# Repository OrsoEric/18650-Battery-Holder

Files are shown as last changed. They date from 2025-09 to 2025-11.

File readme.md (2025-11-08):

# 18650 Battery Holder

This is a design for a robot battery holder

# Battery with PCB protection

Length measured to the tip of the button

| Battery | Diameter [mm] | Length [mm] | Capacity [mAh] | Note |
|---|---|---|---|---|
| UltraFlre LI IONBRC  |  18 | 680 | 4800 | I think the capacity is a scam|
| RSPRO LI ION PCB |  18 | 710 | 2600 | |

# Battery Tab 

Size 11x11mm slightly bigger

| Loading | Length [mm] |
|---|---|
| Unloaded | 8 mm |
| Loaded | 3 mm |

# OpenSCAD

Modeling of the parts

## Tab with Spring

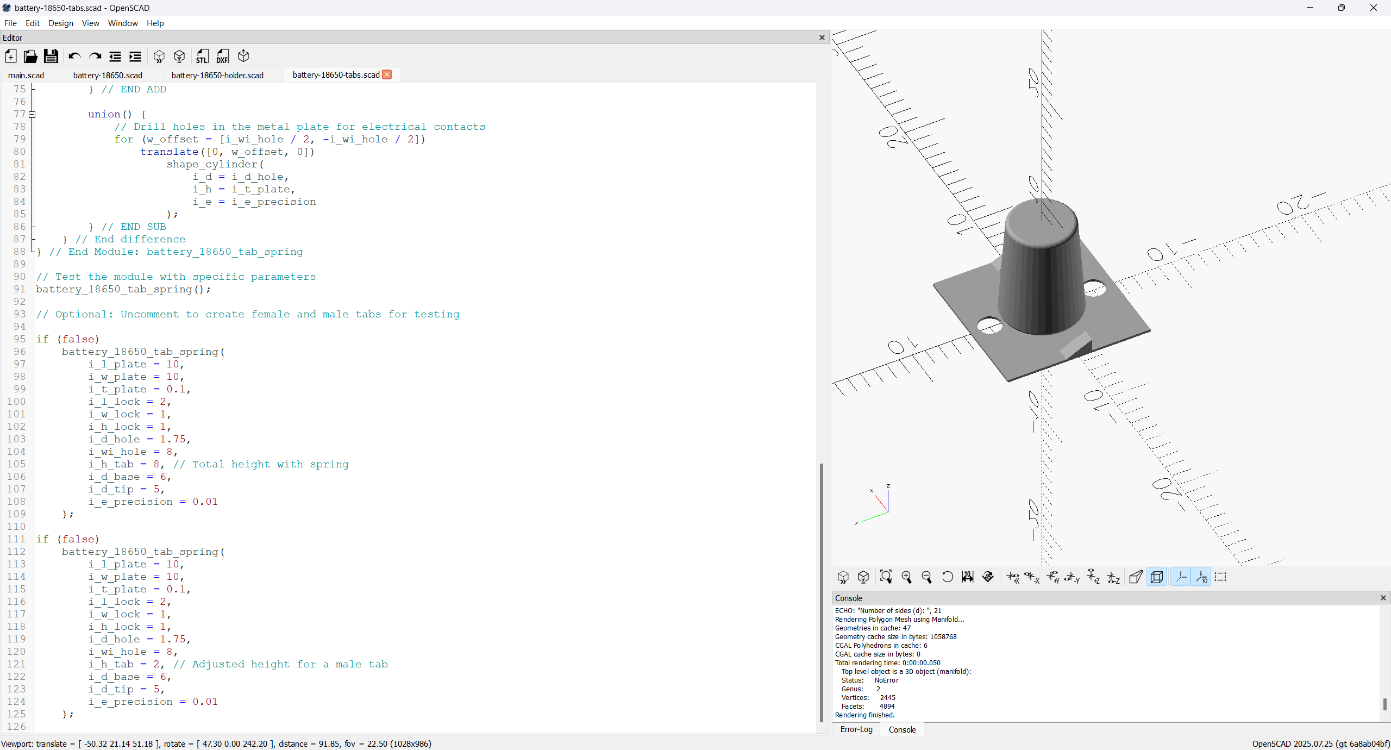
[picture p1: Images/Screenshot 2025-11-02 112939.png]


## Endcap for the battery holder

OpenSCAD

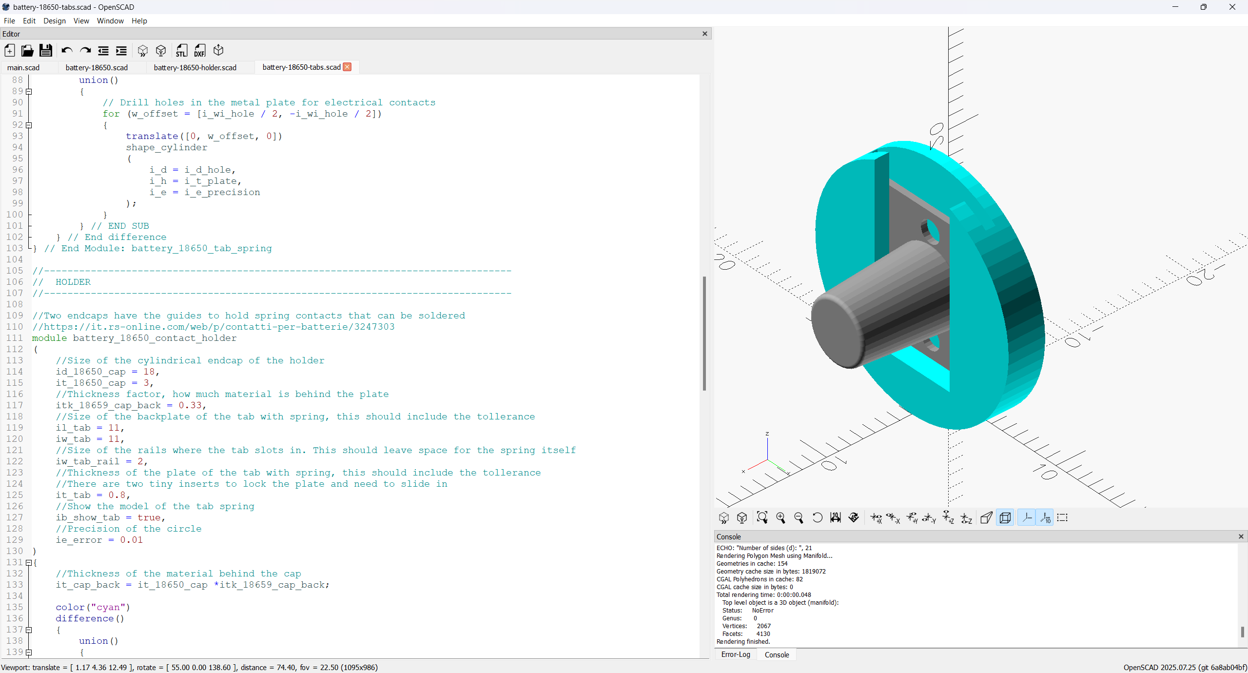
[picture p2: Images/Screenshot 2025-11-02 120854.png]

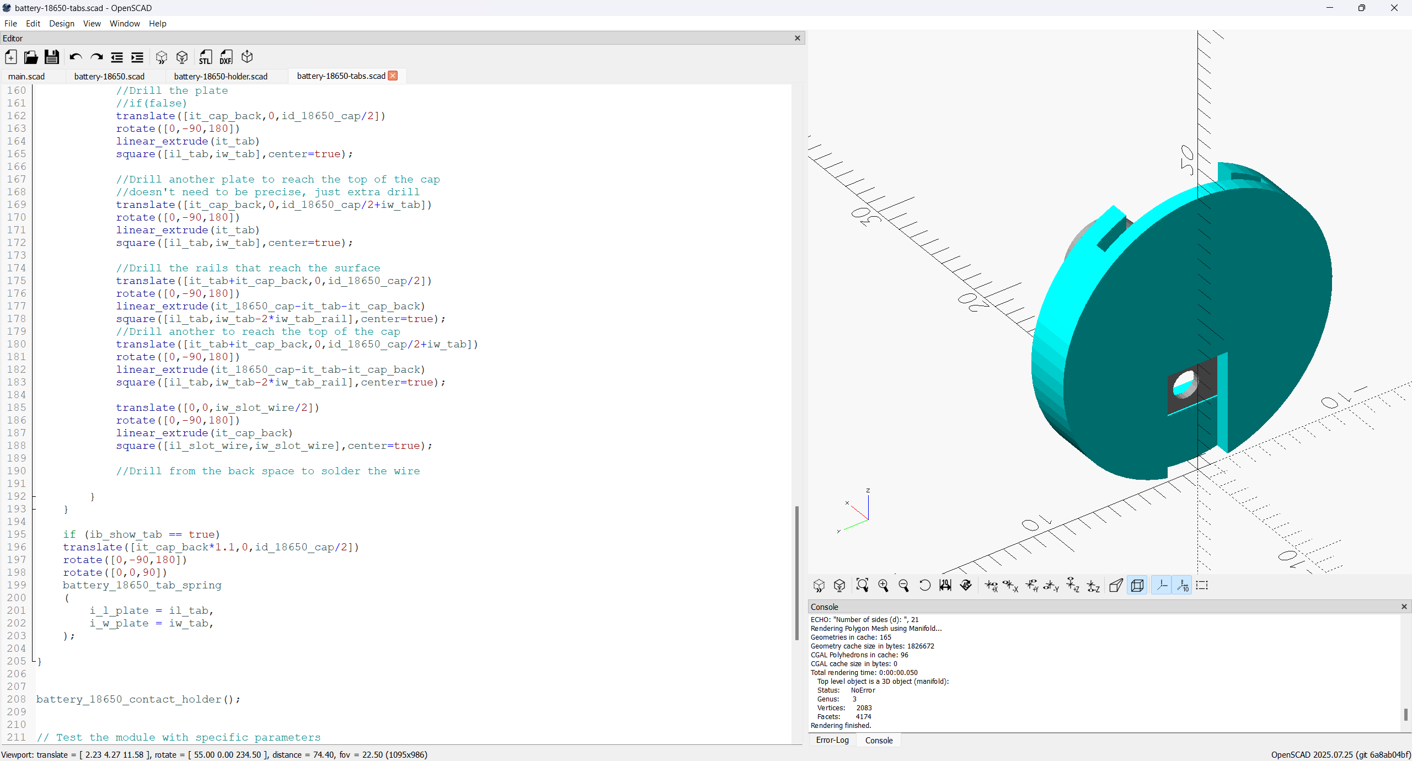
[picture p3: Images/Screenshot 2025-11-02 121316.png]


Printed to test tollerances

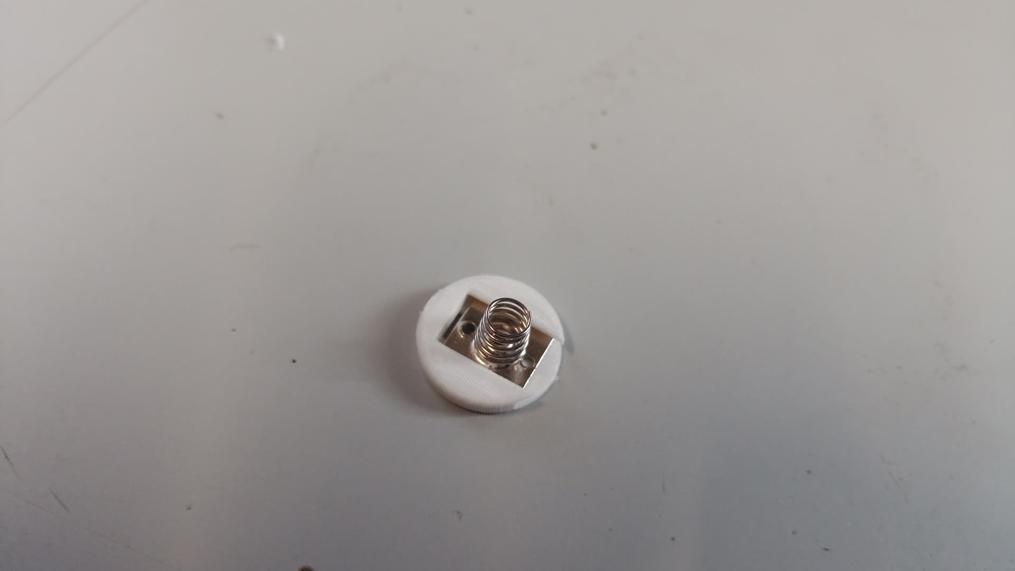
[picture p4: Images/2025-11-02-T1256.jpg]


## Holder 1S1P Single Battery

S mean series, P means parallel

3.7V nominal
4.2V max

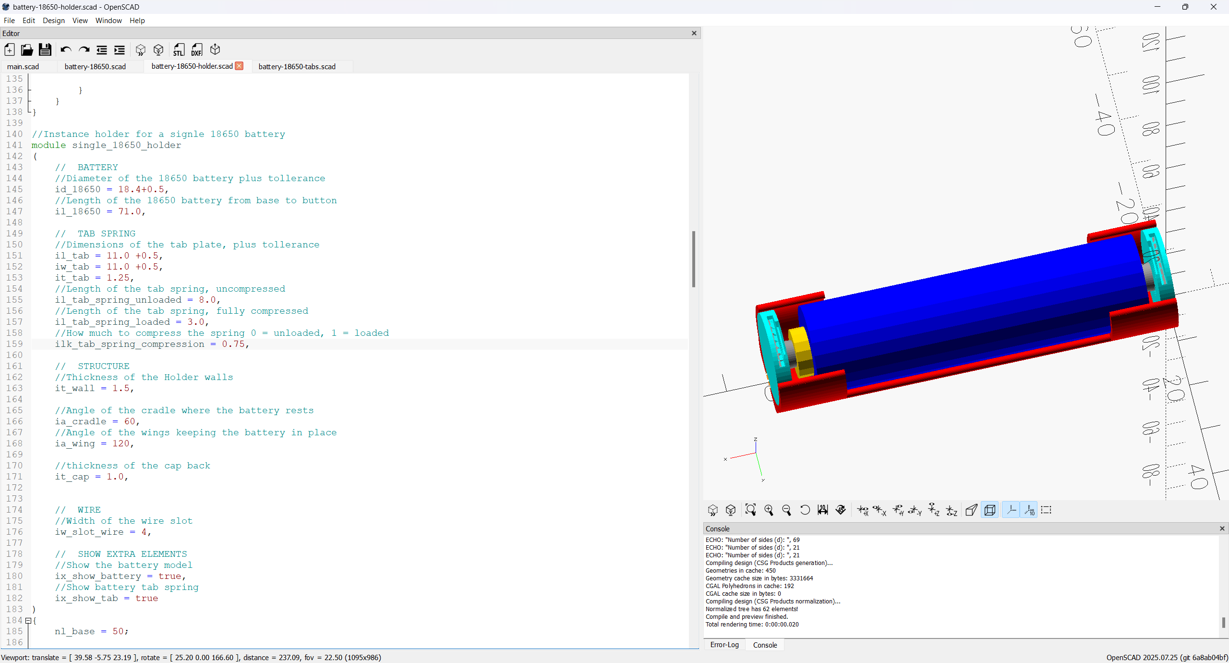
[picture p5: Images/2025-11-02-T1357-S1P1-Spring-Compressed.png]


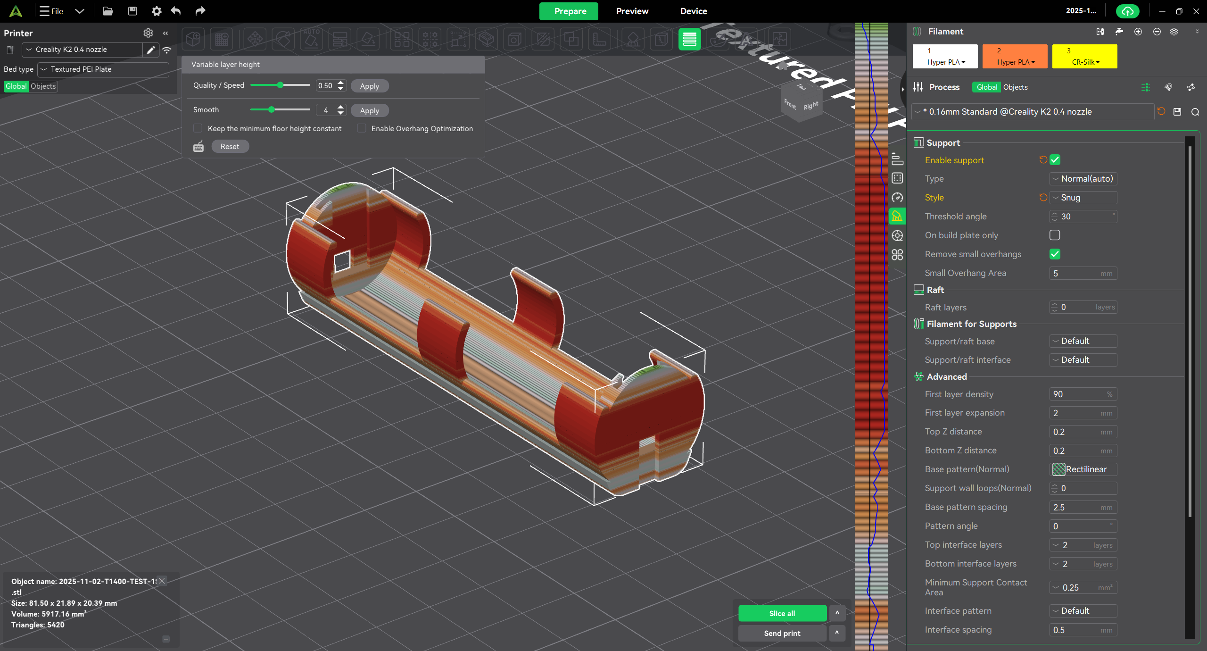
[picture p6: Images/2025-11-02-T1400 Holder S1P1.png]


First test, it's close. Fix:
- I did double spring that's not smart, I do have a button contact for the positive tab
- The center wing is too weak, I need to make it longer
- Ticker construction?

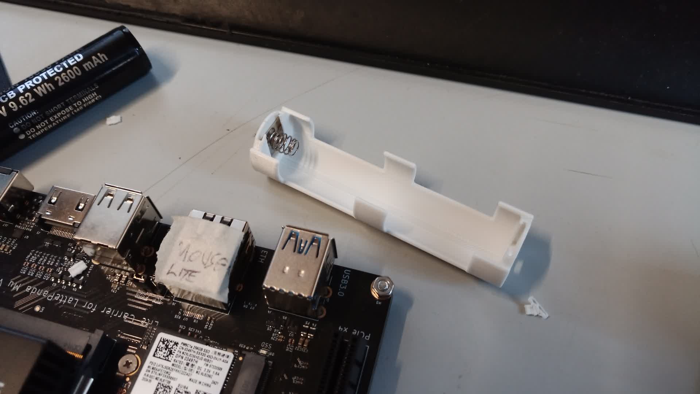
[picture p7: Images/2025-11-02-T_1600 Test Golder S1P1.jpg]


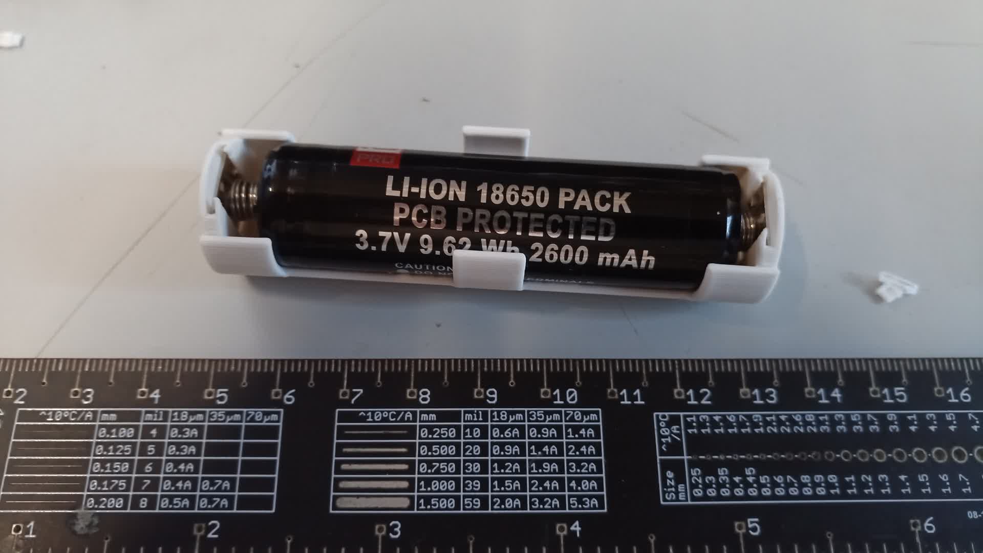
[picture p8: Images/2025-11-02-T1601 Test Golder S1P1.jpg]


## Holder 2S1P Dual Battery

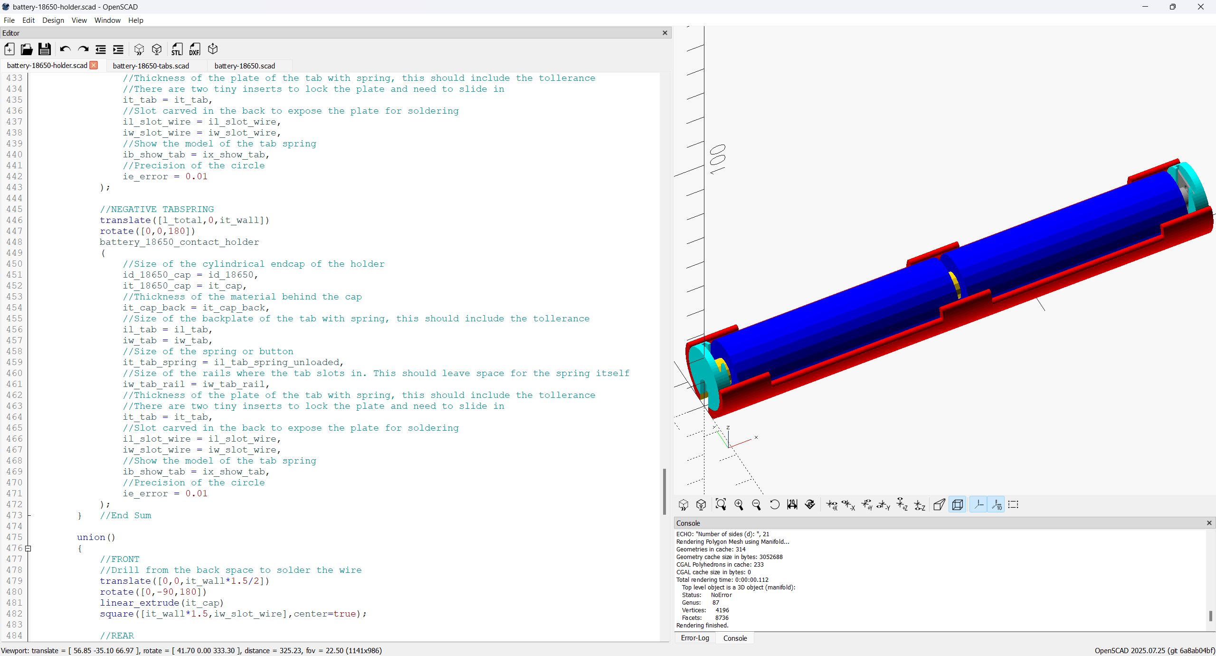
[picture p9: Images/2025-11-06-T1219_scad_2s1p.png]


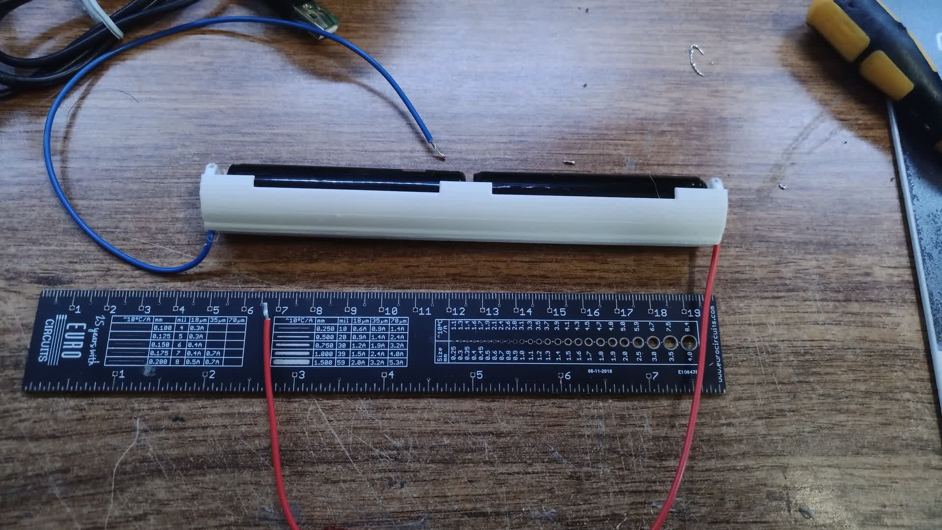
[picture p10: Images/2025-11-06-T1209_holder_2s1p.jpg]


## Holder 2S2P Quad Battery

3.7 * 4 = 14.8V nominal
4.2 * 4 = 16.8V max

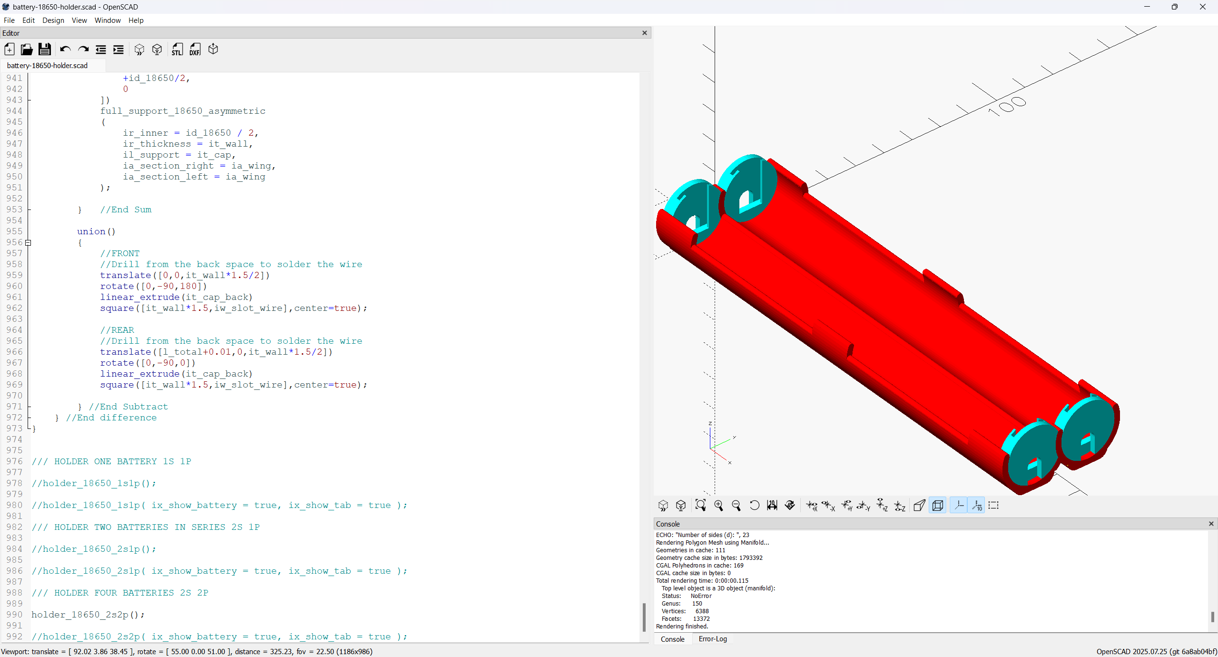
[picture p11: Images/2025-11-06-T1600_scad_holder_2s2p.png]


## Soldering

<video src="/Videos/2025-11-06_18650_Battery_Holder_1S1P_2S2P_Solder_Test.mp4" width="720" height="480" controls></video>

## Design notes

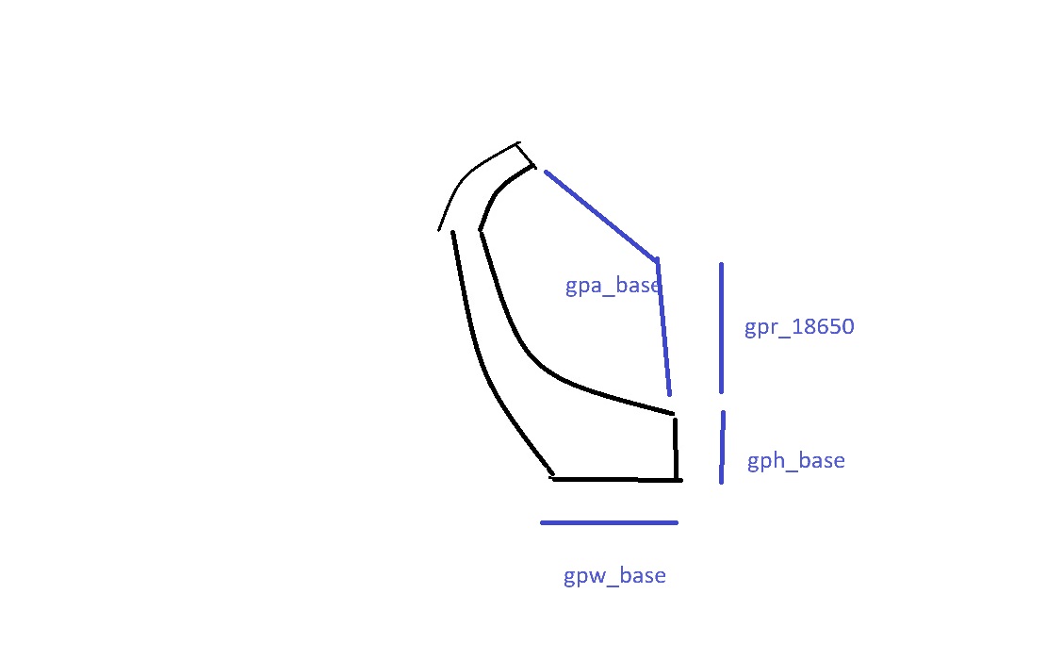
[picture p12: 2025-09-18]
Images/Support Design.jpg

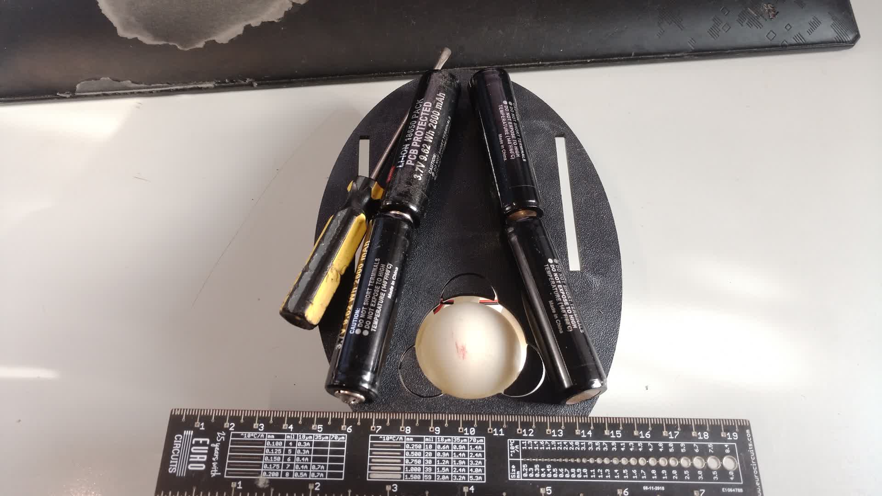
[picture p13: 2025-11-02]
Images/2025-11-02_14_44_IMG_20251102_144404.jpg

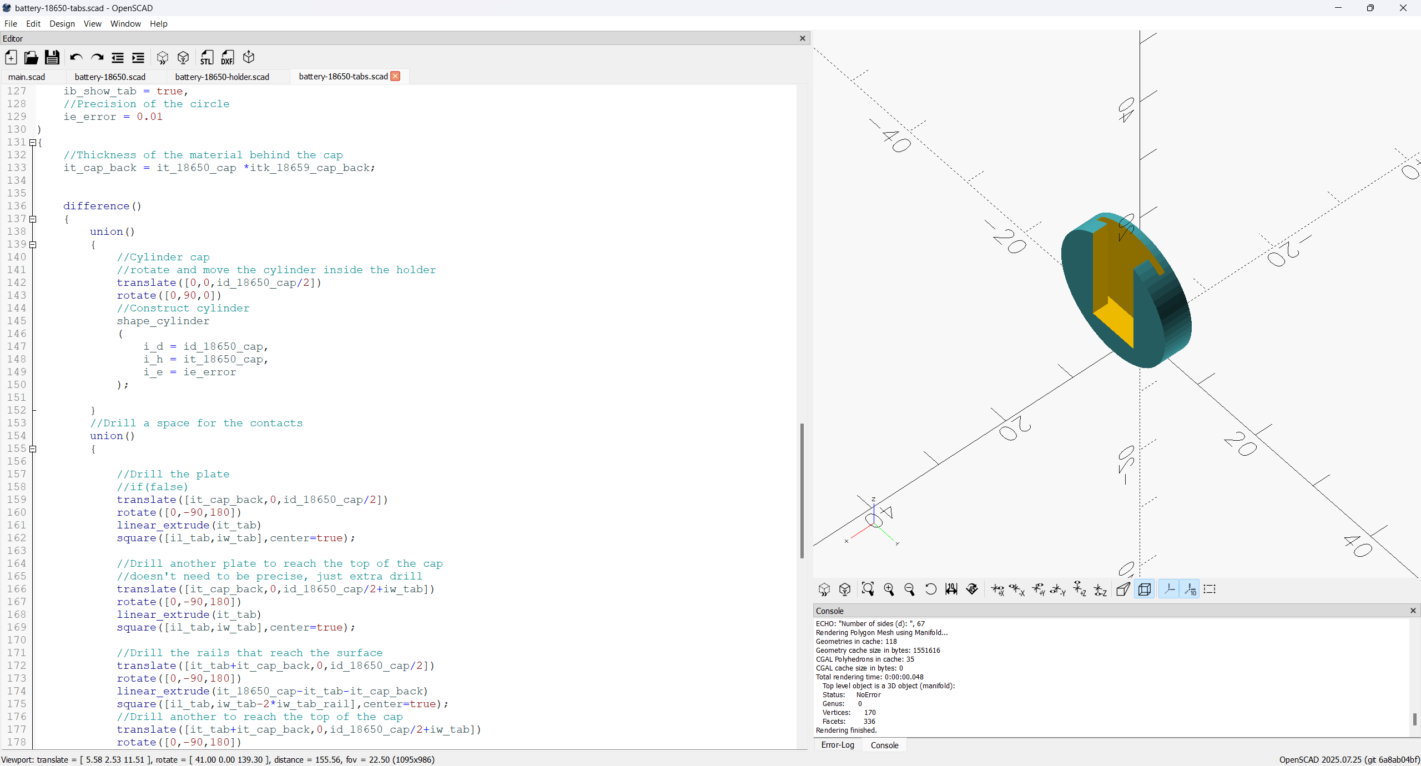
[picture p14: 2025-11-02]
Images/Screenshot 2025-11-02 120257.png

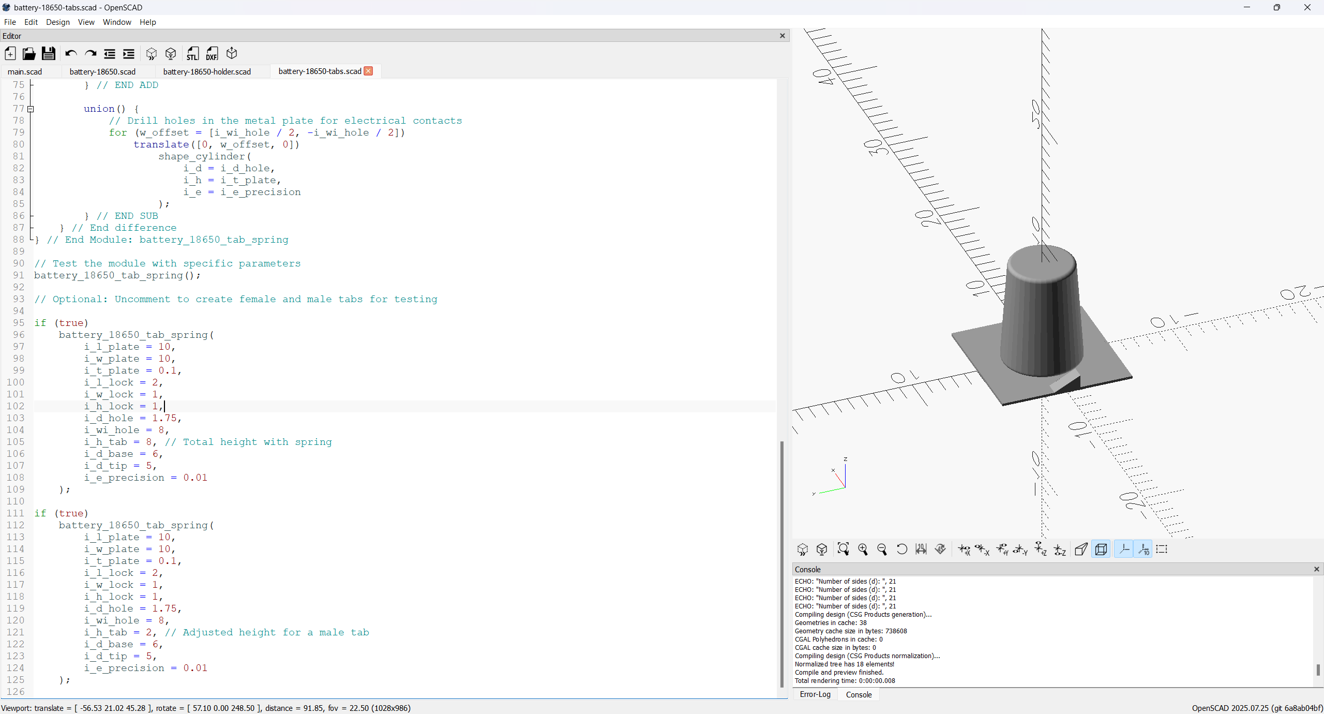
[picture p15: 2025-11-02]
Images/Screenshot 2025-11-02 112849.png

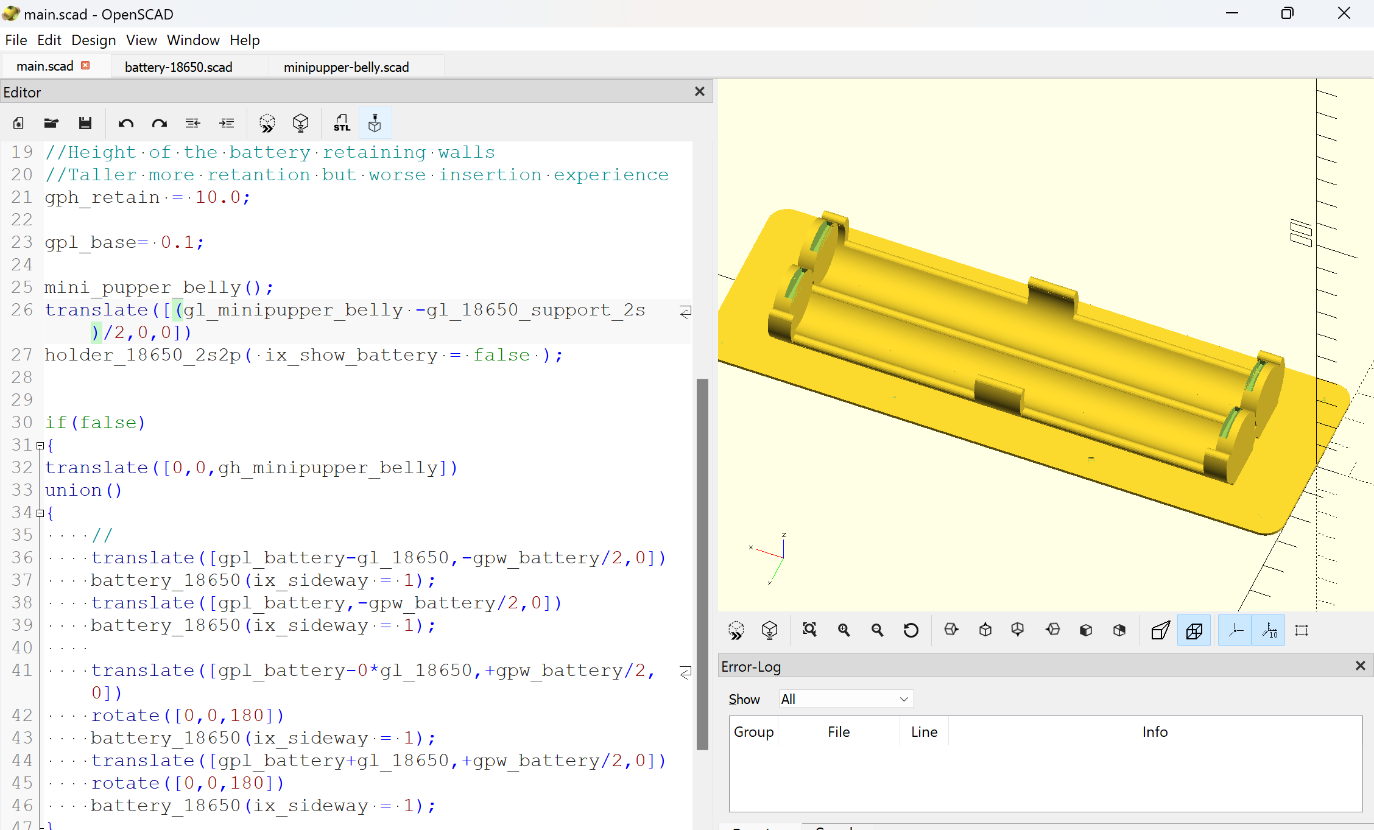
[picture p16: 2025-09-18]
Images/main.scad - OpenSCAD 2024-06-20 18_16_03.png

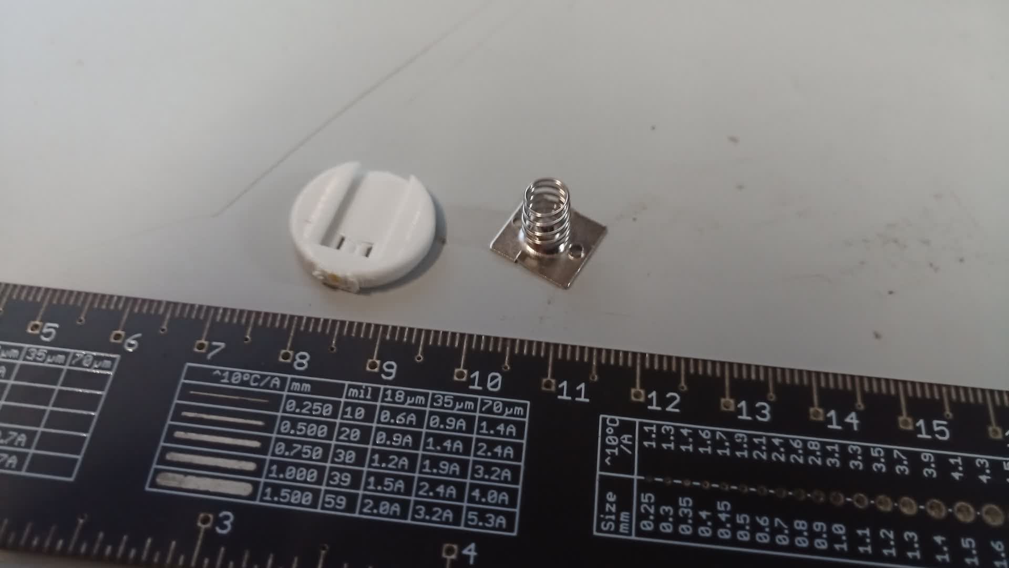
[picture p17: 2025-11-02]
Images/2025-11-02_12_37_IMG_20251102_123743.jpg

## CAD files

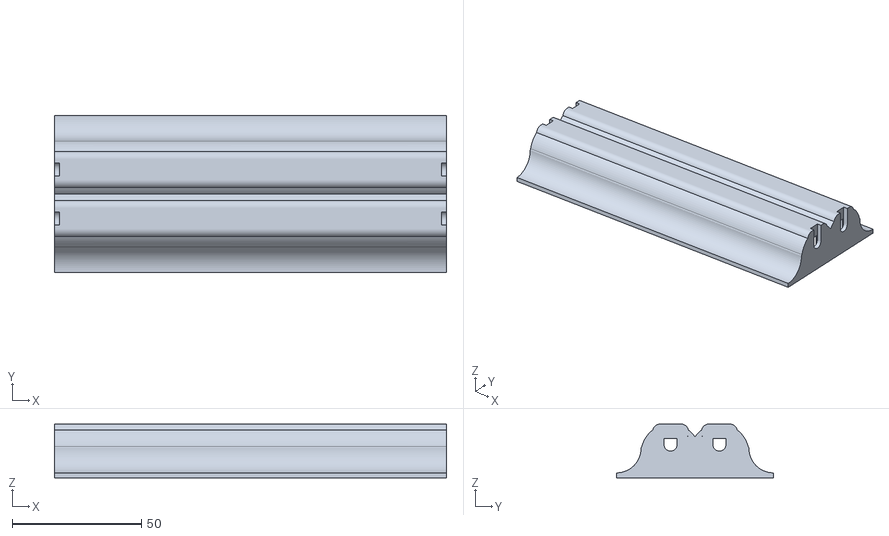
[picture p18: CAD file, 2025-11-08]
stl/2025-11-08-T1028-2S2P_inverted.stl
151.8 x 60.7 x 20.9

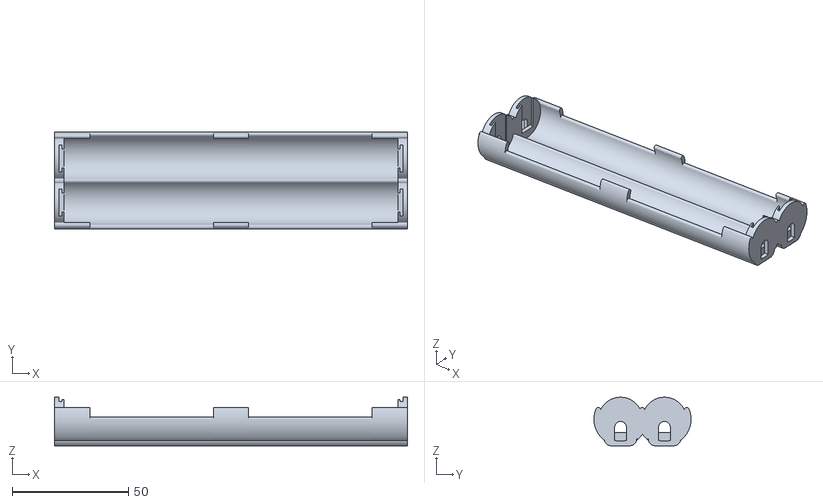
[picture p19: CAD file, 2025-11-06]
stl/2025-11-06-T1600-TEST-2S2P.stl
151.8 x 41.8 x 20.9

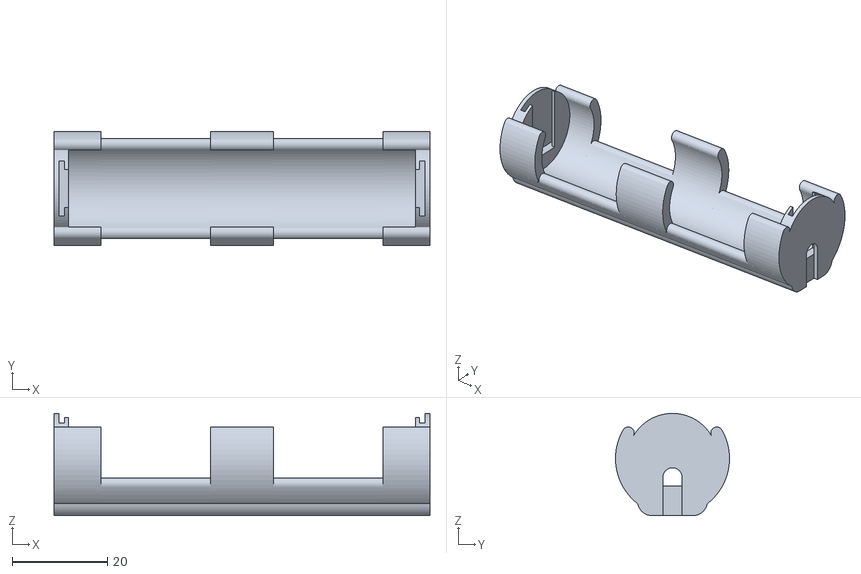
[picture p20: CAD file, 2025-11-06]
stl/2025-11-02-T1650-TEST-1S.stl
78.8 x 23.9 x 21.4

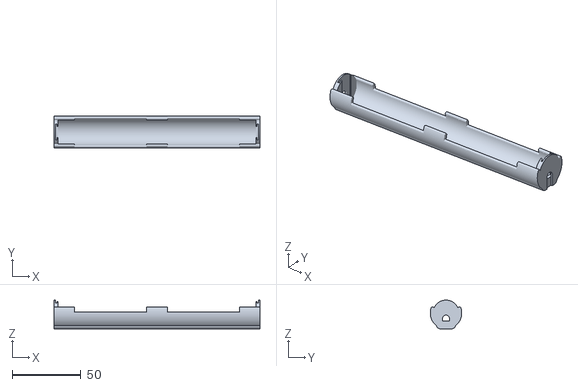
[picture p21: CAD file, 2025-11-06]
stl/2025-11-06-T1120-TEST-2S1P.stl
149.8 x 22.9 x 20.9

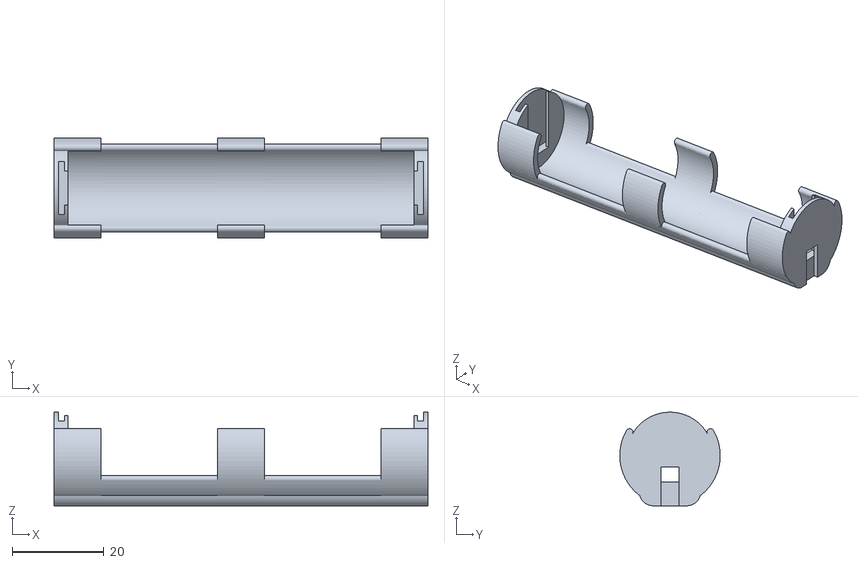
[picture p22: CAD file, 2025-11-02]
stl/2025-11-02-T1400-TEST-1S.stl
81.5 x 21.9 x 20.4

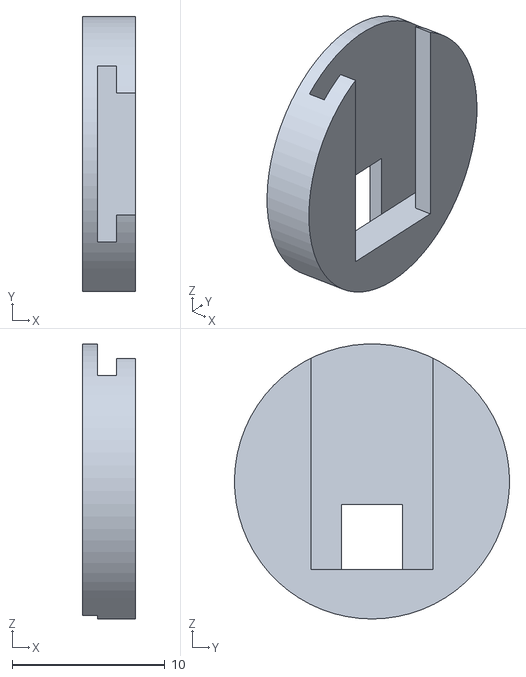
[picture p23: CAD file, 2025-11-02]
stl/2025-11-02-T1309-TEST-Tab-Spring.stl
3.50 x 18.0 x 18.0

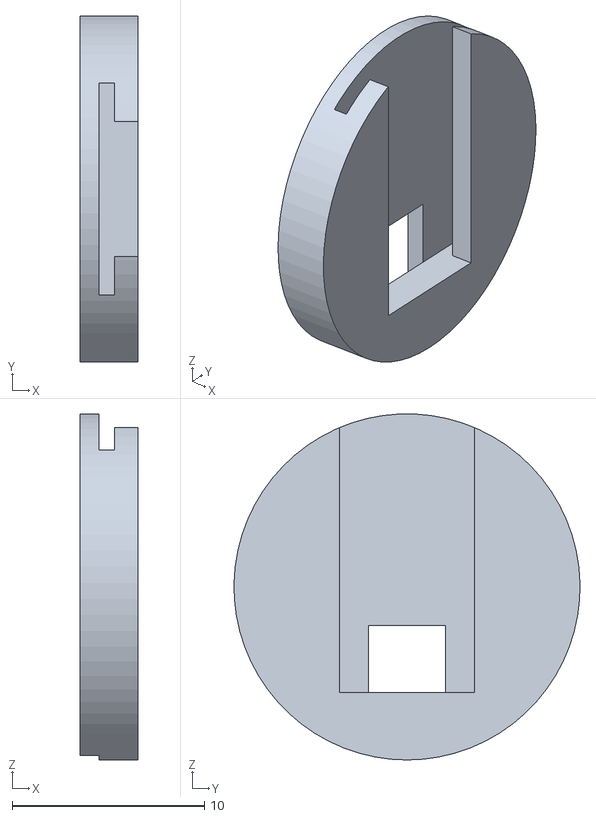
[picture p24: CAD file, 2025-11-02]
stl/2025-11-02-T1215-TEST-Tab-Spring.stl
3.00 x 18.0 x 18.0

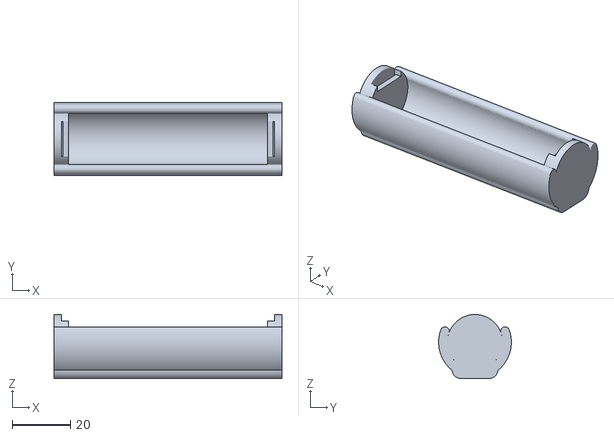
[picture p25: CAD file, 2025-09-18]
stl/2024-06-13_18_21_18650_single_prototype.stl
78.0 x 24.9 x 21.9

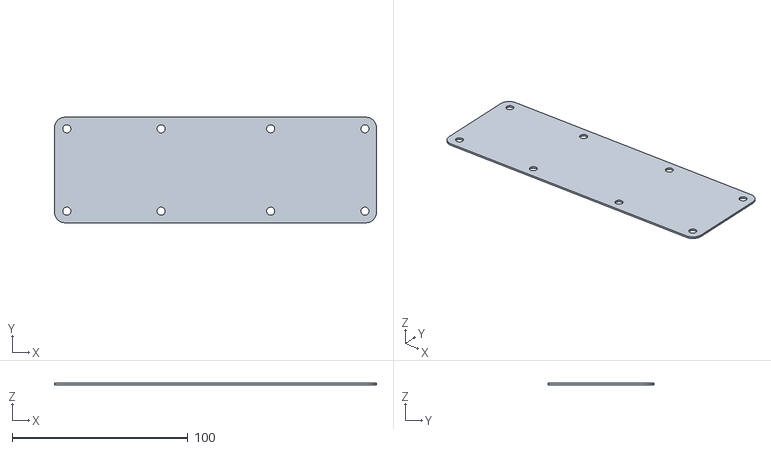
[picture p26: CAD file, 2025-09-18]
stl/2024-06-02 MP2 Belly Plate V0.stl
183.0 x 60.0 x 1.00

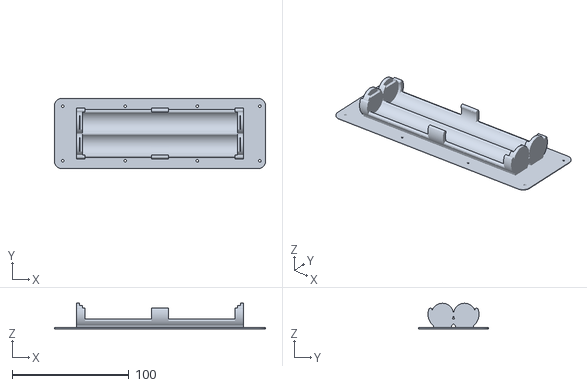
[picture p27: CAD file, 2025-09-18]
stl/2024-06-20_18_17-2s2p-prototype.stl
181.0 x 60.0 x 21.9

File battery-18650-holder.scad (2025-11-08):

include <libs/polyround.scad>

include <libs/shape_petal.scad>

include <battery-18650.scad>

//Include the geometry for the tab that contact with the battery, and the endcap of the battery holder
include <battery-18650-tabs.scad>

//	2024-06-23
//	Printed but too short for the batteries

//ia_section = controls the strength of the support. 0 is none. 90 comes up to half battery. the more up the more it retains, but the harder it is to insert
//Fixed the shape of the base to be more scalable with wall thickness, now works from 1 to 3
module half_support_18650
(
	ir_inner,
	ir_thickness,
	il_support,
	ia_section
)
{
    aan_points =
	([
        //Origin
        [0,0,0],
        [0,ir_thickness,0],
		[-ir_inner*0.5 -ir_thickness*0.7,ir_thickness,3],
        [-ir_inner*0.6 -ir_thickness*0.9,-0.2*ir_inner,0],
		[-ir_inner*0.3 -ir_thickness*0.4,-0.0*ir_inner,0],
        [-ir_inner*0.5 -ir_thickness*0.7,-0.0*ir_inner,0],
    ]);  

    //Place the base under the battery housing
    translate([0,0,ir_thickness])
    rotate([-90,0,-90])
    //Construct base
    linear_extrude(il_support)
    polygon(polyRound(aan_points,100));

	shape_petal
	(
		i_r_inner = ir_inner,
		i_r_thickness = ir_thickness,
		i_l_length =il_support,
		i_a_angle = ia_section,
		i_e = 0.01
	);
}

if (false)
half_support_18650
(
	ir_inner = (18.4+0.5)/2,
	ir_thickness = 1.0,
	il_support = 20,
	ia_section = 60
);


//Support around a full battery
module full_support_18650
(
	ir_inner,
	ir_thickness,
	il_support,
	ia_section,
)
{
    half_support_18650(ir_inner, ir_thickness, il_support, ia_section);

    //left wing
    translate([il_support,0,0])
    rotate([0,0,180])
    half_support_18650(ir_inner, ir_thickness, il_support, ia_section);
}

//Support around a full battery
module full_support_18650_asymmetric
(
	ir_inner,
	ir_thickness,
	il_support,
	ia_section_right,
	ia_section_left
)
{
    half_support_18650(ir_inner, ir_thickness, il_support, ia_section_right);

    //left wing
    translate([il_support,0,0])
    rotate([0,0,180])
    half_support_18650(ir_inner, ir_thickness, il_support, ia_section_left);
}

//Instance holder for a signle 18650 battery
module holder_18650_1s1p
(
	//	BATTERY
	//Diameter of the 18650 battery plus tollerance
	id_18650 = 18.4+0.5,
	//Length of the 18650 battery from base to button
	il_18650 = 71.0,

	//	TAB SPRING/BUTTON
	//Dimensions of the tab plate, plus tollerance
	il_tab = 11.0 +0.5,
	iw_tab = 11.0 +0.5,
	//Thickness of plate slot
	it_tab = 1.25,
	//Size of the button of the tab
	it_tab_button_positive = 1.5,
	//Length of the tab spring, uncompressed
	il_tab_spring_unloaded = 8.0,
	//Length of the tab spring, fully compressed
	il_tab_spring_loaded = 3.0,
	//How much to compress the spring 0 = unloaded, 1 = loaded
	ilk_tab_spring_compression = 0.75,
	//Rails
	iw_tab_rail = 1.75,

	//	STRUCTURE
	//Thickness of the Holder walls
	it_wall = 2.0,
	//Length factor of the wings 10 means 1/10 of length. 5 mean 1/5 of length
	ilk_wing = 6,


	//Angle of the cradle where the battery rests
	ia_cradle = 90,
	//Angle of the wings keeping the battery in place
	ia_wing = 110,
	
	//Thickness of the cap plus rails
	it_cap = 4.0,
	//thickness of the cap back
	it_cap_back = 2.0,
	


	//	WIRE
	//Lentgh of the wire slot
	il_slot_wire = 6,
	//Width of the wire slot
	iw_slot_wire = 5,

	//	SHOW EXTRA ELEMENTS
	//Show the battery model
	ix_show_battery = false,
	//Show battery tab spring
	ix_show_tab = false
)
{
    nl_base = 50;

	//Compute the spring compression length when battery is placed
	il_tab_spring = il_tab_spring_loaded + (il_tab_spring_unloaded -il_tab_spring_loaded)*(1-ilk_tab_spring_compression);
	
	echo("Spring loading",il_tab_spring);
	//Total length of the battery holder. account for the full stack
	l_total = il_18650 + it_cap_back + it_tab_button_positive + il_tab_spring + it_cap_back;

    //battery
    if (ix_show_battery == true)
    {
        //translate([(l_total-il_18650)/2,0,it_wall])
		translate([it_cap_back+it_tab_button_positive,0,it_wall])
        battery_18650
		(
			// Barrel Dimensions
			i_l_18650 = il_18650,
			i_d_18650 = id_18650-0.5,
			ix_sideway = 1,
			in_invert_poles = true
		);
    }
    
    //I use two sets of wings
    //short wings to retain the battery aligned
    //Tall wings to clip the battery in place

	difference()
	{
		union()
		{
			//Retaining wing butt
			color("red")
			full_support_18650
			(
				id_18650 / 2,
				it_wall,
				l_total / ilk_wing,
				ia_wing
			);

			//Retaining wing front
			color("red")
			translate([l_total *(1 -1/ilk_wing),0,0])
			full_support_18650
			(
				id_18650 / 2,
				it_wall,
				l_total / ilk_wing,
				ia_wing
			);

			//Retaining wing center
			if (false)
			color("red")
			translate([l_total *(2.5/6),0,0])
			full_support_18650
			(
				id_18650 / 2,
				it_wall,
				l_total / 6,
				ia_wing
			);

			//Support wing
			color("red")
			full_support_18650
			(
				id_18650/2,
				it_wall,
				l_total,
				ia_cradle
			);

			//POSITIVE TAB BUTTON 
			translate([0,0,it_wall])
			battery_18650_contact_holder
			(
				//Size of the cylindrical endcap of the holder
				id_18650_cap = id_18650,
				it_18650_cap = it_cap,
				//Thickness of the material behind the cap
				it_cap_back = it_cap_back,
				//Size of the backplate of the tab with spring, this should include the tollerance
				il_tab = il_tab,
				iw_tab = iw_tab,
				//Size of the spring or button
				it_tab_spring = it_tab_button_positive,
				//Size of the rails where the tab slots in. This should leave space for the spring itself
				iw_tab_rail = iw_tab_rail,
				//Thickness of the plate of the tab with spring, this should include the tollerance
				//There are two tiny inserts to lock the plate and need to slide in
				it_tab = it_tab,
				//Slot carved in the back to expose the plate for soldering
				il_slot_wire = il_slot_wire,
				iw_slot_wire = iw_slot_wire,
				//Show the model of the tab spring
				ib_show_tab = ix_show_tab,
				//Precision of the circle
				ie_error = 0.01
			);

			//NEGATIVE TABSPRING
			translate([l_total,0,it_wall])
			rotate([0,0,180])
			battery_18650_contact_holder
			(
				//Size of the cylindrical endcap of the holder
				id_18650_cap = id_18650,
				it_18650_cap = it_cap,
				//Thickness of the material behind the cap
				it_cap_back = it_cap_back,
				//Size of the backplate of the tab with spring, this should include the tollerance
				il_tab = il_tab,
				iw_tab = iw_tab,
				//Size of the spring or button
				it_tab_spring = il_tab_spring_unloaded,
				//Size of the rails where the tab slots in. This should leave space for the spring itself
				iw_tab_rail = iw_tab_rail,
				//Thickness of the plate of the tab with spring, this should include the tollerance
				//There are two tiny inserts to lock the plate and need to slide in
				it_tab = it_tab,
				//Slot carved in the back to expose the plate for soldering
				il_slot_wire = 5.5,
				iw_slot_wire = iw_slot_wire,
				//Show the model of the tab spring
				ib_show_tab = ix_show_tab,
				//Precision of the circle
				ie_error = 0.01
			);
		}	//End Sum

		union()
		{
			//FRONT
			//Drill from the back space to solder the wire
			translate([0,0,it_wall*1.5/2])
			rotate([0,-90,180])
			linear_extrude(it_cap_back)
			square([it_wall*1.5,iw_slot_wire],center=true);

			//REAR
			//Drill from the back space to solder the wire
			translate([l_total+0.01,0,it_wall*1.5/2])
			rotate([0,-90,0])
			linear_extrude(it_cap_back)
			square([it_wall*1.5,iw_slot_wire],center=true);

		} //End Subtract

	} //End difference
	
}

//----------------------------------------------------------------------------
//	2S 1P
//----------------------------------------------------------------------------

//Instance holder for a signle 18650 battery
module holder_18650_2s1p
(
	//	BATTERY
	//Diameter of the 18650 battery plus tollerance
	id_18650 = 18.4+0.5,
	//Length of the 18650 battery from base to button
	il_18650 = 71.0,

	//	TAB SPRING/BUTTON
	//Dimensions of the tab plate, plus tollerance
	il_tab = 11.0 +0.5,
	iw_tab = 11.0 +0.5,
	//Thickness of plate slot
	it_tab = 1.25,
	//Size of the button of the tab
	it_tab_button_positive = 1.5,
	//Length of the tab spring, uncompressed
	il_tab_spring_unloaded = 8.0,
	//Length of the tab spring, fully compressed
	il_tab_spring_loaded = 3.0,
	//How much to compress the spring 0 = unloaded, 1 = loaded
	ilk_tab_spring_compression = 0.75,
	//Rails
	iw_tab_rail = 1.75,

	//	STRUCTURE
	//Thickness of the Holder walls
	it_wall = 2.0,
	//Length factor of the wings 10 means 1/10 of length. 5 mean 1/5 of length
	ilk_wing = 10,

	//Angle of the cradle where the battery rests
	ia_cradle = 90,
	//Angle of the wings keeping the battery in place
	ia_wing = 110,
	
	//Thickness of the cap plus rails
	it_cap = 4.0,
	//thickness of the cap back
	it_cap_back = 2.0,

	//	WIRE
	//Lentgh of the wire slot
	il_slot_wire = 6,
	//Width of the wire slot
	iw_slot_wire = 5,
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

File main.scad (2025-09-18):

//MiniPupper 2 battery plate with 18650 batteries
//2S 2P configuration

//TODO MP plate holes

include <minipupper-belly.scad>

include <libs/battery-18650.scad>

//
gpl_battery = 100;
gpw_battery = 20;

//Support for 18650
//size of the flat base
gpw_base = 10;
//Thickness of the base
gph_base = 2;
//Height of the battery retaining walls
//Taller more retantion but worse insertion experience
gph_retain = 10.0;

gpl_base= 0.1;

mini_pupper_belly();
translate([(gl_minipupper_belly -gl_18650_support_2s)/2,0,0])
holder_18650_2s2p( ix_show_battery = false );


if(false)
{
translate([0,0,gh_minipupper_belly])
union()
{
    //
    translate([gpl_battery-gl_18650,-gpw_battery/2,0])
    battery_18650(ix_sideway = 1);
    translate([gpl_battery,-gpw_battery/2,0])
    battery_18650(ix_sideway = 1);
    
    translate([gpl_battery-0*gl_18650,+gpw_battery/2,0])
    rotate([0,0,180])
    battery_18650(ix_sideway = 1);
    translate([gpl_battery+gl_18650,+gpw_battery/2,0])
    rotate([0,0,180])
    battery_18650(ix_sideway = 1);
}
}
//translate([200,0,0])
//half_support_18650();

//half_support_18650( 65/2, 3, 200, 100 );

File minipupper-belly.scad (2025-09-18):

//Mini pupper
//Belly plate for 3D printing

include <polyround.scad>

//Dimensions
//Global Length
gl_minipupper_belly = 181.0;
//Global Width
gw_minipupper_belly = 60.0;
//Global height
gh_minipupper_belly = 1.0;

//Drill pattern
gpl_drill_front = 0.5*(51.5+55.7);
gpl_drill_center = 0.5*(60.1+64.3)-0.25;
gpl_drill_rear = 0.5*(51.4+55.8);
gpw_drill = 0.5*(44.6+49.0);
//Margin drill border
gml_drill_front = 7.0;
gml_drill_rear = 4.0;
gm2_drill = 6.5;

//Global Diameter
gd_minipupper_belly_drill = 2.0 +0.3;
//Global Pitch Length/Width
gpl_minipupper_belly_drill = 10 *8 /2;
gpw_minipupper_belly_drill = 6 *8;

module drill( ind, inz, in_precision = 0.5 )
{
    linear_extrude(inz)
    circle( d=ind, $fa=in_precision, $fs=in_precision );
}

module mini_pupper_belly( inr_rounding = 6.0, in_precision = 0.5 )
{
    
    aan_points =
	([
        [0, -0.5*gw_minipupper_belly, inr_rounding],
        [0, +0.5*gw_minipupper_belly, inr_rounding],
		[+gl_minipupper_belly, +0.5*gw_minipupper_belly, inr_rounding],
		[+gl_minipupper_belly, -0.5*gw_minipupper_belly, inr_rounding],
    ]);
	
    difference()
    {
        union()
        {
            linear_extrude(gh_minipupper_belly)
            polygon(polyRound(aan_points,100));
        }
        union()
        {
			//Front Drills
			translate([gml_drill_front,0.5*gpw_drill,0])
			drill(gd_minipupper_belly_drill, gh_minipupper_belly, in_precision);
			translate([gml_drill_front,-0.5*gpw_drill,0])
			drill(gd_minipupper_belly_drill, gh_minipupper_belly, in_precision);

			//Center Front Drills
			translate([gml_drill_front+gpl_drill_front,0.5*gpw_drill,0])
			drill(gd_minipupper_belly_drill, gh_minipupper_belly, in_precision);
			translate([gml_drill_front+gpl_drill_front,-0.5*gpw_drill,0])
			drill(gd_minipupper_belly_drill, gh_minipupper_belly, in_precision);

			//Center Rear Drills
			translate([gml_drill_front+gpl_drill_front+gpl_drill_center,0.5*gpw_drill,0])
			drill(gd_minipupper_belly_drill, gh_minipupper_belly, in_precision);
			translate([gml_drill_front+gpl_drill_front+gpl_drill_center,-0.5*gpw_drill,0])
			drill(gd_minipupper_belly_drill, gh_minipupper_belly, in_precision);

			//Rear Drills
			translate([gml_drill_front+gpl_drill_front+gpl_drill_center+gpl_drill_rear,0.5*gpw_drill,0])
			drill(gd_minipupper_belly_drill, gh_minipupper_belly, in_precision);
			translate([gml_drill_front+gpl_drill_front+gpl_drill_center+gpl_drill_rear,-0.5*gpw_drill,0])
			drill(gd_minipupper_belly_drill, gh_minipupper_belly, in_precision);	        
        }
    }
    
	
    
}

//mini_pupper_belly();

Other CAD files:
stl/2025-11-02-T1240-TEST-Tab-Spring.stl
battery-18650-tabs.scad
battery-18650.scad

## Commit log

2025-09-18 continuing from the 18650 battery design for pupper
    [2024-06-02 MP2 Belly Plate V0.stl, 2024-06-13_18_21_18650_single_prototype.stl, 2024-06-20_18_17-2s2p-prototype.stl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]
2025-09-18 encapsulated the petal shape
    [battery-18650-holder.scad, main.scad]
2025-09-19 created geometry for the tab. Improved the shape linbraries
    [battery-18650-tabs.scad]
2025-11-02 Redesigned the endcap to accomodate the spring cap and working out tollerances
    [2025-11-02-T1215-TEST-Tab-Spring.stl, 2025-11-02-T1240-TEST-Tab-Spring.stl, 2025-11-02-T1309-TEST-Tab-Spring.stl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]
2025-11-02 added the endcap to the single holder S1P1 improved the geometry, lengthed the wings, and thinned the walls redone the calculations to use spring compression percentage to compute size of the battery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
    [2025-11-02-T1400-TEST-1S.stl, battery-18650-holder.scad, battery-18650-tabs.scad]
2025-11-02 test print, some fixes to do I need to think how to place batteries on the robots
2025-11-06 Improved design, designed and tested 2S1P and soldered it works
    [2025-11-02-T1650-TEST-1S.stl, 2025-11-06-T1120-TEST-2S1P.stl, battery-18650-holder.scad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]
2025-11-06 building 2S 2P battery holder
    [battery-18650-holder.scad]
2025-11-06 First release of the 2S 2P battery
    [2025-11-06-T1600-TEST-2S2P.stl, battery-18650-holder.scad]
2025-11-08 Added screenshots
    [battery-18650-holder.scad]
2025-11-08 Document 1S1P 2S1P 2S2P tested and soldered
2025-11-08 designed inverted 2S2P TODO: I need to drill the wire passage on the regular 2S2P P.S. I connect them 4S1P even
    [2025-11-08-T1028-2S2P_inverted.stl, battery-18650-holder.scad]
